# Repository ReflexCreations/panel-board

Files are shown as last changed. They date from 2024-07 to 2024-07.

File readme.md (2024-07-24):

# RE:Flex Dance Panel v2 PCB Design 

This repository contains source documents and manufacturing files for the RE:Flex Dance Pad's Panel Board. It was created using [KiCAD 5.1.4](https://kicad.org/).

The Panel Boards purpose is to implement three subsystems underneath a standard dance pad 'panel':
- An interface for four [GML670 50kg Load Cell Sensors](http://www.gavincc.com/galoce/category-1/140.html). This subsystem conditions and amplifies the sensor differential input signals to prevent noise interference. The system is then sampled by an ADC at approximately 64kHz, and averaged to produce a clear 1kHz signal.
- Interface for a diamond-shaped grid of 84 RGB WS2813 LEDs at over 60Hz. On-board implementation of a 24->5V switch-mode power supply allows interface of standard brick PSUs to power a given board. There is also a 5V logic system for generating timing data that allows control of the RGB LED data.
- Interface for UART over RJ45, to communicate data from the I/O board for LED animations and to communicate data back to the I/O board for sensor data. The I/O USB interface allows for the generation of lighting data by computer program, and subsequent use of the analog sensor data gathered by Panel boards.

2. Place the order with [JLCPCB](https://jlcpcb.com)
```
    Open https://jlcpcb.com/ in your web browser.
    Click "Order Now" in the upper-right of the screen.
    Click "Add your gerber file", select the release-v2-RC2.zip file from the releases.
    Pick a PCB Qty.  It has to be a multiple of 5.  You will need 4 panel boards per platform.  Note that the per-board cost may reduce quite dramatically as you increase your order size.
    Pick a board color or leave it at the default green. Last time I checked different colors only affect build time, not price.
    Pick a surface finish or leave it on the default. The default is cheapest, but contains lead. ENIG gives the pads a nice golden finish instead of silver.
    Leave all the other options as they are.
    Scroll down to "SMT Assembly" and switch it on.  This means they will solder components on the board for you.  But not necessarily all of them.
    Select "assemble top side"
    Pick a quantity (SMT QTY).  If you picked 5 for the PCB Qty, you can choose to have only 2 assembled, to save money on parts and assembly fees.  Otherwise all of them will be assembled.
    Click "Confirm".
    On the right side of the page, click "Next"
    Click "Add BOM File"; upload the *release/bom.csv* file
    Click "Add CPL File"; upload the the *release/panel-board-top-pos.csv* file
    Click "Next"
    Review the specified parts; they should all be "confirmed" in the right column, so you can leave everything as it is.
        It's IMPORTANT to check this page carefully, as stock shortages are not at all uncommon, and will be reported on this page.
        If you proceed without addressing such issues, your order will go ahead but the missing components will be left out of the assembly process.  You will not be charged for these components, but they will not be mounted on your board either.
        Also note that this page only considers a single board when giving the cost for each component.  Don't worry.  The actual per-component cost you are charged will be based on the total quantity of the component mounted on all boards combined.  You will be able to confirm this in the Bill of Materials, viewable from the shopping cart page.
    Click "Next"
        In the preview, some ICs might look like they're oriented wrong. This is a problem with their viewer; the files are correct. If it ends up wrong (not aligning with the pads), they'll either correct it or email you to find a solution.
    Click "Save to cart"
        On the shopping cart page, you can access the Bill of Material for the SMT assembly, which will show exactly what you pay for each component.
        If the total cost here is lower than you expected, take it as a sign to double-check the Bill of Material and the "Unselected Parts" in the next tab, and look for parts that should have been supplied by JLCPCB but weren't.
    Click "Check out Securely"
    Add your shipping and billing details
    Select a shipping method. Usually the DHL-based ones are fine. You can gamble on whether or not you want duty and customs paid up front (more expensive), or hope for the best with the cheaper option, in which case you might get a bill from the courier later.
    Click "Continue" when you're happy
    Click "submit order"
    Do what you need to do for payment
    Wait for your boards to get delivered
```

3. Order the remaining through-hole parts - A list of these parts can be seen at `release/unpopulated.csv`. Companies that sell parts like this include Mouser, Digikey, RS-Components and Farnell.

4. Solder the remaining parts onto the board.  For some parts, you may need to work out a way to keep them from falling out from the board when you flip it upside-down to do the soldering.  I've heard of techniques including heat-resistant tape, folded paper towels and blu-tack.  You'll work something out, but keep in mind each method has its caveats, and don't forget you're dealing with a hot soldering iron, so take care.
    Here is a guide for each through-hole part on the panel board:
    J1 / Würth Elektronik 694106301002 / 2.1mm DC barrel jack connector: Easy.  Big contacts can take a lot of solder.
    J2 / Amphenol FCI 54602-908LF / Rj45/ethernet connector: Snaps onto the board with plastic tabs so you don't have to worry about holding it in place.  These large components can get in the way when soldering other components, so consider doing them last.
    J3 / 3M 30310-6002HB / 10-pin ST-LINK connector with plastic fence: By convention, the gap in the fence goes on the side with pin 1 - the pin with the square solder pad.  The gap also faces towards the edge of the board in this instance.
    J4 / Harwin M20-9980446 / External Logic connector: It's quite possible you'll never use this connector, so you could consider postponing this one until you actually need it, which might also reduce the chance of damage to the 74HCT245 level-shifter chip from ESD.  This one falls right out if not held in place, so you'll want to apply some technique as touched on above.
    J5,J6,J7,J8 / Japan Solderless Terminals B4B-PH-K-S(LF)(SN) / load cell sensor connectors: The gap in the fence goes towards the inside of the board.  If you're looking at the side of the connector with that gap, pin 1 is on the right.  Unless you're holding it upside-down.  Just point the gap towards the middle of the board and you'll be okay.  Though they have a little grip, I'd recommend you take steps (see above) to keep them in place when soldering.
    SW1,SW2 / TE Connectivity 1825910-6: The pins lock into the board so you don't have to worry about it falling out of position.  When these switches are placed correctly, the pins come out on the left and right sides.  It's possible to bend the pins the wrong way if you're careless during insertion, but it's easy to rectify.

## Future Improvements
- Under test, several boards had broken level shifters / microcontrollers due to ESD under improper handling. This shouldn't be a problem if taking proper ESD precaution. Reducing susceptibility to ESD would be important to improve reliability of these boards for end users, though.
- The LEDs don't need to be powered by 5V. Running 4V is perfectly reasonable. And running the microcontroller at 3.6V could remove the requirement for the level shifter IC. This'd save money and complexity.
- Currently, there's a lot of connectors. We could daisy chain a number of boards if we utilized the correct UART transmission protocol. My hope is eventually to just have 3 RJ45 connectors, which can each address a maximum of 3 panels. 
- Switching to lower power LEDs would be nice. Currently they're far too bright and reducing their power consumption could make some things easier.
- We could also eliminate the need for all of the output DC power jacks by running power along the RJ45 cable, similar to 'Power over Ethernet'. This would probably depend on using low power LEDs.
- Step-down converter update. Currently it's a bit unwieldy. With lower power LEDs we could switch the electrolytics for an array of multiceramics to improve reliability. This would also be necessary for the daisy chaining method.
- The RS-485 transceivers probably don't need direction-switching, and the transceiver is entirely deprecated connected to the USART clock lines. We could save some microcontroller pins by removing this. This'd also make firmware updates to panel boards over UART a lot easier.
- Setting a panel 'address' via DIP switches. This'd make it easier to transfer information back about the sensor data, and allow the panel to be identified by software as a 'Left' or 'Up-Right' or any other type of panel. Especially useful for future daisy chained 9 panel implementations.
- Easier debugging. The status LEDs are ambiguous as to what they do. More status LEDs, more text indication on the board (e.g. 'Active UART comms' next to a status LED) could make things a lot easier for the end user.
- Future form factor updates. People might want to use these boards in an arcade pad. They may want to avoid the aluminium extrusion framework. Fitting this board for all sorts of different requirements will improve accessibility to the electronics.
- Board that doesn't need LEDs, or use external LED power source for running the panels. This will make things significantly cheaper for other variants. This board could also avoid the expensive conditioning of load cells if it could interface FSRs and digital sensors. 
- These boards could have through hole parts populated by a batch manufacturer, and be sold without the need for soldering. If you'd like to sell these boards, please get in touch, and we can help you source finished boards.

## Firmware

For the board to function, you will need to install the panel board firmware to it. You can find this information within the repo for the Panel-Firmware.

## License

For license details, see LICENSE file

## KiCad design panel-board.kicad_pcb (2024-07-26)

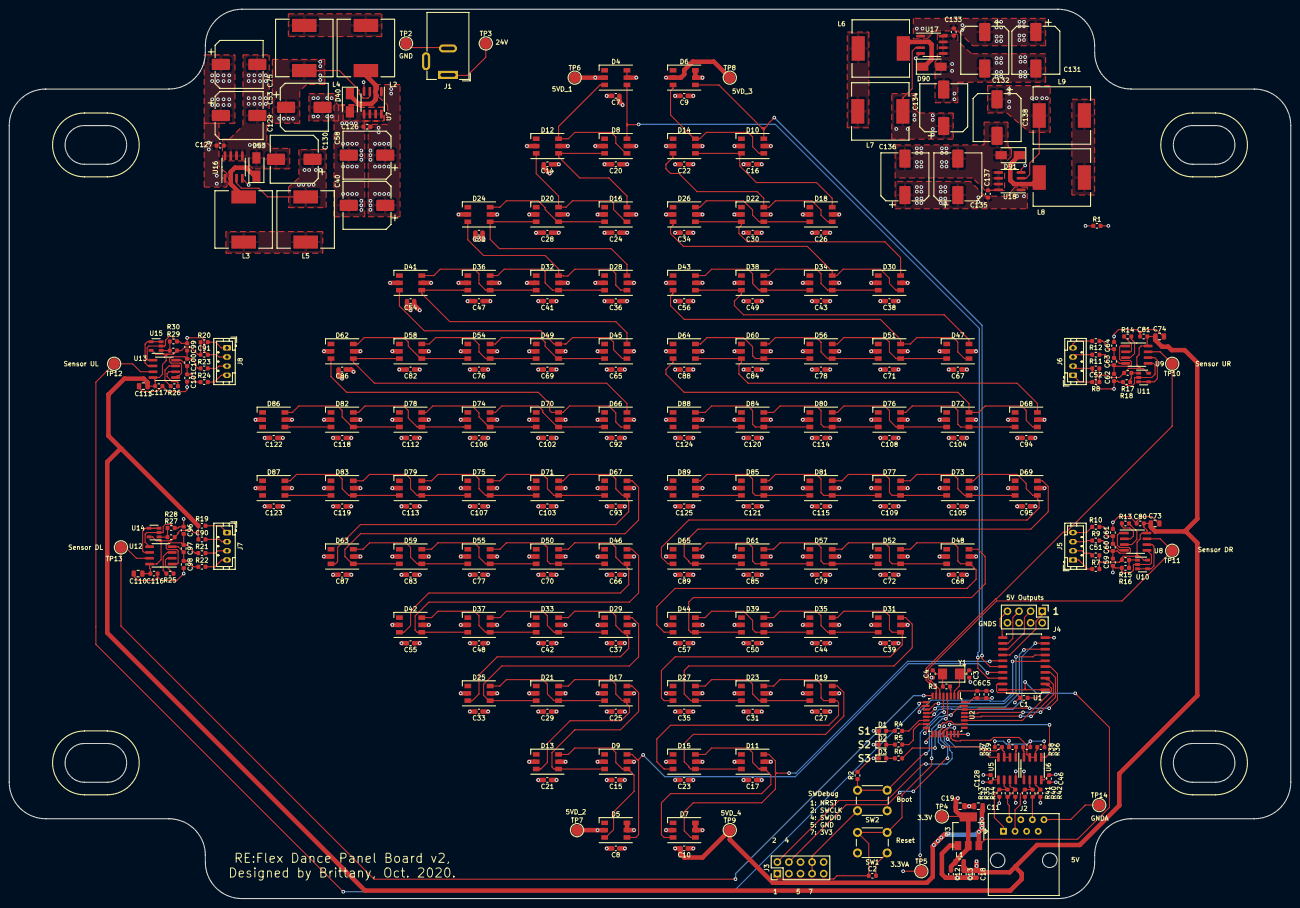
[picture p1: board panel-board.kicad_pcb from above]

Board: 4 copper layers, 281.0 x 195.0 mm, 318 parts (0 on the bottom side), 176 nets.

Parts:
C1, C2, C5, C6, C7, C8, C9, C10, C14, C15, C16, C17, C18, C20, C21, C22, C23, C24, C25, C26, C27, C28, C29, C30, C31, C32, C33, C34, C35, C36, C37, C38, C39, C41, C42, C43, C44, C46, C47, C48, C49, C50, C51, C52, C54, C55, C56, C57, C65, C66, C67, C68, C69, C70, C71, C72, C76, C77, C78, C79, C80, C81, C82, C83, C84, C85, C86, C87, C88, C89, C90, C91, C92, C93, C94, C95, C102, C103, C104, C105, C106, C107, C108, C109, C112, C113, C114, C115, C116, C117, C118, C119, C120, C121, C122, C123, C124, C125, C126, C127, C128, C133, C137: 0.1u; C_0603_1608Metric
C3, C4: 22p; C_0603_1608Metric
C11, C73, C74, C110, C111: 10u; C_0805_2012Metric
C12, C13: 1u; C_0603_1608Metric
C19: 22u; C_0805_2012Metric
C40, C53, C58, C75, C129, C130, C131, C132, C134, C135, C136, C138: 220u; CP_Elec_10x10
C59, C61, C62, C64, C96, C98, C99, C101: 4.7n; C_0603_1608Metric
C60, C63, C97, C100: 470n; C_0603_1608Metric
D1, D2, D3: LED_Small; LED_0603_1608Metric
D4, D5, D6, D7, D8, D9, D10, D11, D12, D13, D14, D15, D16, D17, D18, D19, D20, D21, D22, D23, D24, D25, D26, D27, D28, D29, D30, D31, D32, D33, D34, D35, D36, D37, D38, D39, D41, D42, D43, D44, D45, D46, D47, D48, D49, D50, D51, D52, D54, D55, D56, D57, D58, D59, D60, D61, D62, D63, D64, D65, D66, D67, D68, D69, D70, D71, D72, D73, D74, D75, D76, D77, D78, D79, D80, D81, D82, D83, D84, D85, D86, D87, D88, D89: WS2813; LED_WS2812_PLCC6_5.0x5.0mm_P1.6mm
D40, D53, D90, D91: D_Schottky; D_SMA
J1: Barrel_Jack_MountingPin; BarrelJack_Wuerth_6941xx301002
J2: RJ45; RJ45_Amphenol_54602-x08_Horizontal
J3: Conn_02x05_Odd_Even; PinHeader_2x05_P2.54mm_Vertical
J4: Conn_02x04_Odd_Even; PinHeader_2x04_P2.54mm_Vertical
J5, J6, J7, J8: Conn_01x04_Male; JST_PH_B4B-PH-K_1x04_P2.00mm_Vertical
L1: SDFL2012Q1R0KTF; L_0805_2012Metric
L2, L3, L4, L5, L6, L7, L8, L9: 47u; L_12x12mm_H8mm
R1: 0R; R_0603_1608Metric
R2, R16, R18, R28, R30, R36, R37, R38, R39: 10k; R_0603_1608Metric
R3: 220R; R_0603_1608Metric
R4, R5, R6: 270R; R_0603_1608Metric
R7, R8, R19, R20: 470R; R_0603_1608Metric
R9, R10, R11, R12, R21, R22, R23, R24: 330R; R_0603_1608Metric
R13, R14, R25, R26, R35, R40: 100R; R_0603_1608Metric
R15, R17, R27, R29: 33k; R_0603_1608Metric
R41, R42, R43, R44: 360R; R_0603_1608Metric
SW1, SW2: SW_Push; SW_PUSH_6mm
TP2, TP3, TP4, TP5, TP6, TP7, TP8, TP9, TP10, TP11, TP12, TP13, TP14: TestPoint; TestPoint_Pad_D2.5mm
U1: 74HCT245; SOIC-20W_7.5x12.8mm_P1.27mm
U2: STM32F334K8Tx; LQFP-32_7x7mm_P0.8mm
U3: AMS1117-3.3; SOT-223-3_TabPin2
U5, U6: SP3485EN; SOIC-8_3.9x4.9mm_P1.27mm
U7, U16, U17, U18: XL1509-5.0E1; SOIC-8_3.9x4.9mm_P1.27mm
U8, U9, U12, U13: INA826; SOIC-8_3.9x4.9mm_P1.27mm
U10, U11, U14, U15: LMV321; SOT-23-5
Y1: 8MHz; Crystal_SMD_5032-2Pin_5.0x3.2mm

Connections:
5VD_1: C7.2, C14.2, C20.2, C24.2, C28.2, C32.2, C36.2, C41.2, C47.2, C54.2, C65.2, C69.2, C76.2, C82.2, C86.2, C92.2, C102.2, C106.2, C112.2, C118.2, C122.2, C129.1, D4.2 (VDD), D8.2 (VDD), D12.2 (VDD), D16.2 (VDD), D20.2 (VDD), D24.2 (VDD), D28.2 (VDD), D32.2 (VDD), D36.2 (VDD), D41.2 (VDD), D45.2 (VDD), D49.2 (VDD), D54.2 (VDD), D58.2 (VDD), D62.2 (VDD), D66.2 (VDD), D70.2 (VDD), D74.2 (VDD), D78.2 (VDD), D82.2 (VDD), D86.2 (VDD), L4.1, TP6.1, U7.3 (FB)
5VD_2: C8.2, C15.2, C21.2, C25.2, C29.2, C33.2, C37.2, C42.2, C48.2, C55.2, C66.2, C70.2, C77.2, C83.2, C87.2, C93.2, C103.2, C107.2, C113.2, C119.2, C123.2, C130.1, D5.2 (VDD), D9.2 (VDD), D13.2 (VDD), D17.2 (VDD), D21.2 (VDD), D25.2 (VDD), D29.2 (VDD), D33.2 (VDD), D37.2 (VDD), D42.2 (VDD), D46.2 (VDD), D50.2 (VDD), D55.2 (VDD), D59.2 (VDD), D63.2 (VDD), D67.2 (VDD), D71.2 (VDD), D75.2 (VDD), D79.2 (VDD), D83.2 (VDD), D87.2 (VDD), L5.1, TP7.1, U16.3 (FB)
5VD_3: C9.2, C16.2, C22.2, C26.2, C30.2, C34.2, C38.2, C43.2, C49.2, C56.2, C67.2, C71.2, C78.2, C84.2, C88.2, C94.2, C104.2, C108.2, C114.2, C120.2, C124.2, C134.1, D6.2 (VDD), D10.2 (VDD), D14.2 (VDD), D18.2 (VDD), D22.2 (VDD), D26.2 (VDD), D30.2 (VDD), D34.2 (VDD), D38.2 (VDD), D43.2 (VDD), D47.2 (VDD), D51.2 (VDD), D56.2 (VDD), D60.2 (VDD), D64.2 (VDD), D68.2 (VDD), D72.2 (VDD), D76.2 (VDD), D80.2 (VDD), D84.2 (VDD), D88.2 (VDD), L7.1, TP8.1, U17.3 (FB)
5VD_4: C1.1, C10.2, C11.1, C17.2, C23.2, C27.2, C31.2, C35.2, C39.2, C44.2, C50.2, C57.2, C68.2, C72.2, C79.2, C85.2, C89.2, C95.2, C105.2, C109.2, C115.2, C121.2, C125.2, C138.1, D7.2 (VDD), D11.2 (VDD), D15.2 (VDD), D19.2 (VDD), D23.2 (VDD), D27.2 (VDD), D31.2 (VDD), D35.2 (VDD), D39.2 (VDD), D44.2 (VDD), D48.2 (VDD), D52.2 (VDD), D57.2 (VDD), D61.2 (VDD), D65.2 (VDD), D69.2 (VDD), D73.2 (VDD), D77.2 (VDD), D81.2 (VDD), D85.2 (VDD), D89.2 (VDD), L9.1, TP9.1, U1.1 (A->B), U1.20 (VCC), U3.3 (VI), U18.3 (FB)
+3.3V: C5.2, C6.2, C12.1, C19.1, C46.2, C128.2, J3.7, J3.8, L1.1, R39.2, R41.2, R43.2, SW2.1, TP4.1, U2.1 (VDD), U2.17 (VDD), U3.2 (VO), U5.8 (VCC), U6.8 (VCC)
+3.3VA: C13.1, C18.1, C51.1, C52.1, C73.1, C74.1, C80.1, C81.1, C90.1, C91.1, C110.1, C111.1, C116.1, C117.1, L1.2, R7.2, R8.2, R15.2, R17.2, R19.2, R20.2, R27.2, R29.2, TP5.1, U2.5 (VDDA), U8.8 (Vs+), U9.8 (Vs+), U10.5 (V+), U11.5 (V+), U12.8 (Vs+), U13.8 (Vs+), U14.5 (V+), U15.5 (V+)
+24V: C40.1, C53.1, C58.1, C75.1, C126.1, C127.1, C131.1, C132.1, C133.1, C135.1, C136.1, C137.1, J1.1, TP3.1, U7.1 (VIN), U16.1 (VIN), U17.1 (VIN), U18.1 (VIN)
EXTERN1: J4.1, U1.14 (B4)
EXTERN1_3.3: U1.6 (A4), U2.10 (PA4)
EXTERN2: J4.3, U1.13 (B5)
EXTERN2_3.3: U1.7 (A5), U2.11 (PA5)
EXTERN3: J4.5, U1.12 (B6)
EXTERN3_3.3: U1.8 (A6), U2.12 (PA6)
EXTERN4: J4.7, U1.11 (B7)
EXTERN4_3.3: U1.9 (A7), U2.13 (PA7)
GND: C7.1, C8.1, C9.1, C10.1, C14.1, C15.1, C16.1, C17.1, C20.1, C21.1, C22.1, C23.1, C24.1, C25.1, C26.1, C27.1, C28.1, C29.1, C30.1, C31.1, C32.1, C33.1, C34.1, C35.1, C36.1, C37.1, C38.1, C39.1, C40.2, C41.1, C42.1, C43.1, C44.1, C47.1, C48.1, C49.1, C50.1, C53.2, C54.1, C55.1, C56.1, C57.1, C58.2, C65.1, C66.1, C67.1, C68.1, C69.1, C70.1, C71.1, C72.1, C75.2, C76.1, C77.1, C78.1, C79.1, C82.1, C83.1, C84.1, C85.1, C86.1, C87.1, C88.1, C89.1, C92.1, C93.1, C94.1, C95.1, C102.1, C103.1, C104.1, C105.1, C106.1, C107.1, C108.1, C109.1, C112.1, C113.1, C114.1, C115.1, C118.1, C119.1, C120.1, C121.1, C122.1, C123.1, C124.1, C125.1, C126.2, C127.2, C129.2, C130.2, C131.2, C132.2, C133.2, C134.2, C135.2, C136.2, C137.2, C138.2, D4.5 (GND), D4.6 (BIN), D5.5 (GND), D5.6 (BIN), D6.5 (GND), D6.6 (BIN), D7.5 (GND), D7.6 (BIN), D8.5 (GND), D9.5 (GND), D10.5 (GND), D11.5 (GND), D12.5 (GND), D13.5 (GND), D14.5 (GND), D15.5 (GND), D16.5 (GND), D17.5 (GND), D18.5 (GND), D19.5 (GND), D20.5 (GND), D21.5 (GND), D22.5 (GND), D23.5 (GND), D24.5 (GND), D25.5 (GND), D26.5 (GND), D27.5 (GND), D28.5 (GND), D29.5 (GND), D30.5 (GND), D31.5 (GND), D32.5 (GND), D33.5 (GND), D34.5 (GND), D35.5 (GND), D36.5 (GND), D37.5 (GND), D38.5 (GND), D39.5 (GND), D40.2 (A), D41.5 (GND), D42.5 (GND), D43.5 (GND), D44.5 (GND), D45.5 (GND), D46.5 (GND), D47.5 (GND), D48.5 (GND), D49.5 (GND), D50.5 (GND), D51.5 (GND), D52.5 (GND), D53.2 (A), D54.5 (GND), D55.5 (GND), D56.5 (GND), D57.5 (GND), D58.5 (GND), D59.5 (GND), D60.5 (GND), D61.5 (GND), D62.5 (GND), D63.5 (GND), D64.5 (GND), D65.5 (GND), D66.5 (GND), D67.5 (GND), D68.5 (GND), D69.5 (GND), D70.5 (GND), D71.5 (GND), D72.5 (GND), D73.5 (GND), D74.5 (GND), D75.5 (GND), D76.5 (GND), D77.5 (GND), D78.5 (GND), D79.5 (GND), D80.5 (GND), D81.5 (GND), D82.5 (GND), D83.5 (GND), D84.5 (GND), D85.5 (GND), D86.5 (GND), D87.5 (GND), D88.5 (GND), D89.5 (GND), D90.2 (A), D91.2 (A), J1.2, R1.1, TP2.1, U7.4 (~EN), U7.5 (GND), U7.6 (GND), U7.7 (GND), U7.8 (GND), U16.4 (~EN), U16.5 (GND), U16.6 (GND), U16.7 (GND), U16.8 (GND), U17.4 (~EN), U17.5 (GND), U17.6 (GND), U17.7 (GND), U17.8 (GND), U18.4 (~EN), U18.5 (GND), U18.6 (GND), U18.7 (GND), U18.8 (GND)
GNDA: C1.2, C2.1, C3.1, C4.1, C5.1, C6.1, C11.2, C12.2, C13.2, C18.2, C19.2, C46.1, C51.2, C52.2, C59.1, C61.2, C62.1, C64.2, C73.2, C74.2, C80.2, C81.2, C90.2, C91.2, C96.1, C98.2, C99.1, C101.2, C110.2, C111.2, C116.2, C117.2, C128.1, D1.1 (K), D2.1 (K), D3.1 (K), J2.8, J3.5, J3.6, J4.2, J4.4, J4.6, J4.8, J5.2, J6.2, J7.2, J8.2, R1.2, R2.2, R16.1, R18.1, R28.1, R30.1, R36.2, R37.2, R38.2, R42.2, R44.2, SW1.1, TP14.1, U1.10 (GND), U1.19 (CE), U2.16 (VSS), U2.32 (VSS), U3.1 (GND), U5.5 (GND), U6.5 (GND), U8.5 (Vs-), U9.5 (Vs-), U10.2 (V-), U11.2 (V-), U12.5 (Vs-), U13.5 (Vs-), U14.2 (V-), U15.2 (V-)
LEDA: D4.4 (DIN), D8.6 (BIN), U1.18 (B0)
LEDA_3.3: U1.2 (A0), U2.27 (PB4)
LEDB: D5.4 (DIN), D9.6 (BIN), U1.17 (B1)
LEDB_3.3: U1.3 (A1), U2.28 (PB5)
LEDC: D6.4 (DIN), D10.6 (BIN), U1.16 (B2)
LEDC_3.3: U1.4 (A2), U2.29 (PB6)
LEDD: D7.4 (DIN), D11.6 (BIN), U1.15 (B3)
LEDD_3.3: U1.5 (A3), U2.30 (PB7)
NRST: C2.2, J3.1, SW1.2, U2.4 (NRST)
unnamed: C3.2, U2.2 (PF0), Y1.1
unnamed: C4.2, R3.2, Y1.2
unnamed: C59.2, C60.1, R9.1, U8.1 (-)
unnamed: C60.2, C61.1, R10.1, U8.4 (+)
unnamed: C62.2, C63.1, R11.1, U9.1 (-)
unnamed: C63.2, C64.1, R12.1, U9.4 (+)
unnamed: C96.2, C97.1, R21.1, U12.1 (-)
unnamed: C97.2, C98.1, R22.1, U12.4 (+)
unnamed: C99.2, C100.1, R23.1, U13.1 (-)
unnamed: C100.2, C101.1, R24.1, U13.4 (+)
unnamed: D1.2 (A), R4.2
unnamed: D2.2 (A), R5.2
unnamed: D3.2 (A), R6.2
unnamed: D10.3 (DOUT), D14.4 (DIN), D18.6 (BIN)
unnamed: D6.3 (DOUT), D10.4 (DIN), D14.6 (BIN)
unnamed: D11.3 (DOUT), D15.4 (DIN), D19.6 (BIN)
unnamed: D7.3 (DOUT), D11.4 (DIN), D15.6 (BIN)
unnamed: D12.3 (DOUT), D16.4 (DIN), D20.6 (BIN)
unnamed: D8.3 (DOUT), D12.4 (DIN), D16.6 (BIN)
unnamed: D4.3 (DOUT), D8.4 (DIN), D12.6 (BIN)
unnamed: D13.3 (DOUT), D17.4 (DIN), D21.6 (BIN)
unnamed: D9.3 (DOUT), D13.4 (DIN), D17.6 (BIN)
unnamed: D5.3 (DOUT), D9.4 (DIN), D13.6 (BIN)
unnamed: D14.3 (DOUT), D18.4 (DIN), D22.6 (BIN)
unnamed: D15.3 (DOUT), D19.4 (DIN), D23.6 (BIN)
unnamed: D16.3 (DOUT), D20.4 (DIN), D24.6 (BIN)
unnamed: D17.3 (DOUT), D21.4 (DIN), D25.6 (BIN)
unnamed: D18.3 (DOUT), D22.4 (DIN), D26.6 (BIN)
unnamed: D19.3 (DOUT), D23.4 (DIN), D27.6 (BIN)
unnamed: D20.3 (DOUT), D24.4 (DIN), D28.6 (BIN)
unnamed: D21.3 (DOUT), D25.4 (DIN), D29.6 (BIN)
unnamed: D22.3 (DOUT), D26.4 (DIN), D30.6 (BIN)
unnamed: D23.3 (DOUT), D27.4 (DIN), D31.6 (BIN)
unnamed: D24.3 (DOUT), D28.4 (DIN), D32.6 (BIN)
unnamed: D25.3 (DOUT), D29.4 (DIN), D33.6 (BIN)
unnamed: D26.3 (DOUT), D30.4 (DIN), D34.6 (BIN)
unnamed: D27.3 (DOUT), D31.4 (DIN), D35.6 (BIN)
unnamed: D28.3 (DOUT), D32.4 (DIN), D36.6 (BIN)
unnamed: D29.3 (DOUT), D33.4 (DIN), D37.6 (BIN)
unnamed: D30.3 (DOUT), D34.4 (DIN), D38.6 (BIN)
unnamed: D31.3 (DOUT), D35.4 (DIN), D39.6 (BIN)
unnamed: D32.3 (DOUT), D36.4 (DIN), D41.6 (BIN)
unnamed: D33.3 (DOUT), D37.4 (DIN), D42.6 (BIN)
unnamed: D34.3 (DOUT), D38.4 (DIN), D43.6 (BIN)
unnamed: D35.3 (DOUT), D39.4 (DIN), D44.6 (BIN)
unnamed: D36.3 (DOUT), D41.4 (DIN), D45.6 (BIN)
unnamed: D37.3 (DOUT), D42.4 (DIN), D46.6 (BIN)
unnamed: D38.3 (DOUT), D43.4 (DIN), D47.6 (BIN)
unnamed: D39.3 (DOUT), D44.4 (DIN), D48.6 (BIN)
unnamed: D40.1 (K), L2.1, U7.2 (VOUT)
unnamed: D41.3 (DOUT), D45.4 (DIN), D49.6 (BIN)
unnamed: D42.3 (DOUT), D46.4 (DIN), D50.6 (BIN)
unnamed: D43.3 (DOUT), D47.4 (DIN), D51.6 (BIN)
unnamed: D44.3 (DOUT), D48.4 (DIN), D52.6 (BIN)
unnamed: D45.3 (DOUT), D49.4 (DIN), D54.6 (BIN)
unnamed: D46.3 (DOUT), D50.4 (DIN), D55.6 (BIN)
unnamed: D47.3 (DOUT), D51.4 (DIN), D56.6 (BIN)
unnamed: D48.3 (DOUT), D52.4 (DIN), D57.6 (BIN)
unnamed: D49.3 (DOUT), D54.4 (DIN), D58.6 (BIN)
unnamed: D50.3 (DOUT), D55.4 (DIN), D59.6 (BIN)
unnamed: D51.3 (DOUT), D56.4 (DIN), D60.6 (BIN)
unnamed: D52.3 (DOUT), D57.4 (DIN), D61.6 (BIN)
unnamed: D53.1 (K), L3.1, U16.2 (VOUT)
unnamed: D54.3 (DOUT), D58.4 (DIN), D62.6 (BIN)
unnamed: D55.3 (DOUT), D59.4 (DIN), D63.6 (BIN)
unnamed: D56.3 (DOUT), D60.4 (DIN), D64.6 (BIN)
unnamed: D57.3 (DOUT), D61.4 (DIN), D65.6 (BIN)
unnamed: D58.3 (DOUT), D62.4 (DIN), D66.6 (BIN)
unnamed: D59.3 (DOUT), D63.4 (DIN), D67.6 (BIN)
unnamed: D60.3 (DOUT), D64.4 (DIN), D68.6 (BIN)
unnamed: D61.3 (DOUT), D65.4 (DIN), D69.6 (BIN)
unnamed: D62.3 (DOUT), D66.4 (DIN), D70.6 (BIN)
unnamed: D63.3 (DOUT), D67.4 (DIN), D71.6 (BIN)
unnamed: D64.3 (DOUT), D68.4 (DIN), D72.6 (BIN)
unnamed: D65.3 (DOUT), D69.4 (DIN), D73.6 (BIN)
unnamed: D66.3 (DOUT), D70.4 (DIN), D74.6 (BIN)
unnamed: D67.3 (DOUT), D71.4 (DIN), D75.6 (BIN)
unnamed: D68.3 (DOUT), D72.4 (DIN), D76.6 (BIN)
unnamed: D69.3 (DOUT), D73.4 (DIN), D77.6 (BIN)
unnamed: D70.3 (DOUT), D74.4 (DIN), D78.6 (BIN)
unnamed: D71.3 (DOUT), D75.4 (DIN), D79.6 (BIN)
unnamed: D72.3 (DOUT), D76.4 (DIN), D80.6 (BIN)
unnamed: D73.3 (DOUT), D77.4 (DIN), D81.6 (BIN)
unnamed: D74.3 (DOUT), D78.4 (DIN), D82.6 (BIN)
unnamed: D75.3 (DOUT), D79.4 (DIN), D83.6 (BIN)
unnamed: D76.3 (DOUT), D80.4 (DIN), D84.6 (BIN)
unnamed: D77.3 (DOUT), D81.4 (DIN), D85.6 (BIN)
unnamed: D78.3 (DOUT), D82.4 (DIN), D86.6 (BIN)
unnamed: D79.3 (DOUT), D83.4 (DIN), D87.6 (BIN)
unnamed: D80.3 (DOUT), D84.4 (DIN), D88.6 (BIN)
unnamed: D81.3 (DOUT), D85.4 (DIN), D89.6 (BIN)
unnamed: D82.3 (DOUT), D86.4 (DIN)
unnamed: D83.3 (DOUT), D87.4 (DIN)
unnamed: D84.3 (DOUT), D88.4 (DIN)
unnamed: D85.3 (DOUT), D89.4 (DIN)
unnamed: D90.1 (K), L6.1, U17.2 (VOUT)
unnamed: D91.1 (K), L8.1, U18.2 (VOUT)
unnamed: J5.1, R7.1
unnamed: J5.3, R9.2
unnamed: J5.4, R10.2
unnamed: J6.1, R8.1
unnamed: J6.3, R11.2
unnamed: J6.4, R12.2
unnamed: J7.1, R19.1
unnamed: J7.3, R21.2
unnamed: J7.4, R22.2
unnamed: J8.1, R20.1
unnamed: J8.3, R23.2
unnamed: J8.4, R24.2
unnamed: L2.2, L4.2
unnamed: L3.2, L5.2
unnamed: L6.2, L7.2
unnamed: L8.2, L9.2
unnamed: R2.1, SW2.2, U2.31 (BOOT0)
unnamed: R3.1, U2.3 (PF1)
unnamed: R4.1, U2.14 (PB0)
unnamed: R5.1, U2.15 (PB1)
unnamed: R6.1, U2.26 (PB3)
unnamed: R13.1, U8.2 (Rg)
unnamed: R13.2, U8.3 (Rg)
unnamed: R14.1, U9.2 (Rg)
unnamed: R14.2, U9.3 (Rg)
unnamed: R15.1, R16.2, U10.1 (+)
unnamed: R17.1, R18.2, U11.1 (+)
unnamed: R25.1, U12.2 (Rg)
unnamed: R25.2, U12.3 (Rg)
unnamed: R26.1, U13.2 (Rg)
unnamed: R26.2, U13.3 (Rg)
unnamed: R27.1, R28.2, U14.1 (+)
unnamed: R29.1, R30.2, U15.1 (+)
unnamed: R38.1, U6.4 (DI)
unnamed: R39.1, U5.1 (RO)
unnamed: U8.6 (Ref), U10.3 (-), U10.4
unnamed: U9.6 (Ref), U11.3 (-), U11.4
unnamed: U12.6 (Ref), U14.3 (-), U14.4
unnamed: U13.6 (Ref), U15.3 (-), U15.4
RX+: J2.3, R40.2, R41.1, U6.6 (A)
RX-: J2.6, R40.1, R42.1, U6.7 (B)
RX_EN: R36.1, U2.22 (PA12), U6.2 (~RE), U6.3 (DE)
SENS1: TP11.1, U2.6 (PA0), U8.7
SENS2: TP10.1, U2.7 (PA1), U9.7
SENS3: TP13.1, U2.8 (PA2), U12.7
SENS4: TP12.1, U2.9 (PA3), U13.7
SWCLK: J3.2, U2.24 (PA14)
SWDIO: J3.4, U2.23 (PA13)
TX+: J2.1, R35.2, R43.1, U5.6 (A)
TX-: J2.2, R35.1, R44.1, U5.7 (B)
TX_EN: R37.1, U2.21 (PA11), U5.2 (~RE), U5.3 (DE)
UART_RX: U2.20 (PA10), U6.1 (RO)
UART_TX: U2.19 (PA9), U5.4 (DI)

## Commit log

2020-09-06 Layout complete
    [led-board.kicad_pcb, led-board.sch]
2020-09-06 Output files
    [bom.csv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]
2020-09-07 Transceiver fix + output mask
    [led-board-B_Cu.gbr, led-board-B_Mask.gbr, led-board-Edge_Cuts.gbr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]
2020-09-07 Sanity save
    [led-board.kicad_pcb]
2020-09-07 Post v0.2 order commit
    [bom.csv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]
2020-09-22 LEDs and ADC working, separately
    [led-board.kicad_pcb, led-board.sch]
2020-10-20 Staged for v2 release
    [bom.csv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]
2020-11-08 Supply power externally, and move sensor position
    [panel-board.kicad_pcb, panel-board.sch]
2020-11-08 Re-stage step file
2020-11-08 Positioning update
    [panel-board.kicad_pcb]
2020-12-12 Fix symbol library table, adding INA826 lib
    This fixes a missing symbol in the schematic.
2021-01-20 Change the presentation of questionable techniques to a style of "here's an idea, but I'm no expert and you're ultimately the one responsible for your soldering".
    Important because a reader could easily make the mistake of assuming a single author who is experienced in soldering.
2021-11-08 Update readme.md
    https://forum.kicad.info/t/warning-avoid-all-links-to-kicad-pcb-org-use-kicad-org/31521
2024-07-24 Schem for RS485 circuit corrections
    [panel-board.sch]
2024-07-25 Finish PCB RS-485 fixes
    [panel-board.kicad_pcb, panel-board.sch]
2024-07-25 RS-485 updates: panel board
    [panel-board.kicad_pcb, panel-board.sch]
2024-07-26 RS-485 transceiver fixes - production
    [panel-board.kicad_pcb, panel-board.kicad_sch, panel-board.sch]
